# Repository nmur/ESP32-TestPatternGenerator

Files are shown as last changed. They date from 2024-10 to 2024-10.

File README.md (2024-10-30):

# ESP32-TestPatternGenerator

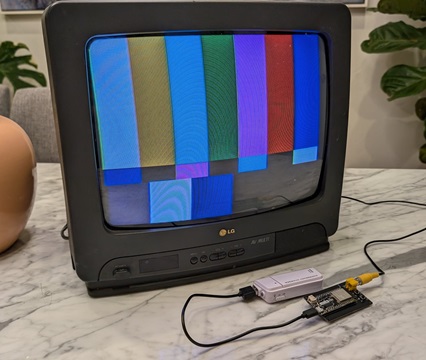
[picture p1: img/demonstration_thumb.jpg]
demonstration
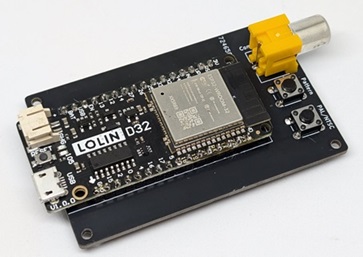
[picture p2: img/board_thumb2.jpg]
board
    

This is a simple test pattern generator that runs on the ESP32 microcontroller and utilises the [ESP32CompositeColorVideo](https://github.com/marciot/ESP32CompositeColorVideo) library to output composite video using either the PAL and NTSC video formats. 

This tool is aimed to be used as a quick and portable was of performing tests of basic functionality for CRT TVs.

Its main features are:
- **Cheap**: Approximately <$10 USD in parts
- **Accessible**: Open source. Only a few components so soldering is easy for a first timer.
- **Small**: Roughly 2x3"/45x80mm in size.
- **Fast**: Boots and changes patterns instantly.
- **Portable**: Very low power draw, works with a powerbank or rechargeable LiPo battery.
- **Versatile**: Supports NTSC and PAL, and provides multiple test patterns.

For a similar tool aimed at 15kHz RGB video, see the [RP2040-TestPatternGenerator](https://github.com/nmur/RP2040-TestPatternGenerator).
## BOM

1. LOLIN D32 board ([Official LOLIN AliExpress store](https://www.aliexpress.us/item/2251832622236364.html), [cheaper listings](https://www.aliexpress.us/item/3256806060247101.html) may be available)
	1. 2x 16 pin headers are usually included
2. 2x 6mm push buttons ([AliExpress](https://www.aliexpress.us/item/2261799870049698.html))
3. Female composite jack ([AliExpress](https://www.aliexpress.us/item/2255800475452071.html))
4. Composite video cable if you don't already have one ([AliExpress](https://www.aliexpress.us/item/3256806419160332.html))
## Building a Board

1. Download the latest [Gerber zip file](https://github.com/nmur/ESP32-TestPatternGenerator/blob/main/plots/ESP32-TestPatternGenerator.zip).
2. Upload and print the Gerber file to a PCB manufacturing website (such as JLCPCB or PCBWay).
3. Solder the components into their marked positions. 

The circuit is simple enough that a PCB isn't necessary, especially if you would just like to try the tool out first with a breadboard or protoboard. You can even splice a composite video cable and wire the ends directly to the ESP32 board pins, and you can omit the buttons if you don't need every pattern (the tool remembers the last video format).

The schematic is available [here](https://raw.githubusercontent.com/nmur/ESP32-TestPatternGenerator/refs/heads/main/img/schematic.png).
## Uploading the Firmware

Navigate to the [Installation page](https://nmur.github.io/ESP32-TestPatternGenerator-WebInstaller/) to connect to your device and flash the firmware from your browser directly. You'll need to install [CH340 drivers](https://www.wch-ic.com/downloads/CH341SER_ZIP.html) in order

## How to Use

Power the device using USB or and LiPo battery, and connect the composite cable to you CRT TV. Cycle through test patterns with the `Pattern` button, and toggle between video formats with the `PAL/NTSC` button. 

The device will remember the last video format so you don't need to toggle it to your region every time it boots.
## Limitations

Currently the available colours are limited to a palette of 256 colours. As such, noticeable colour banding will be present.

## Compiling

1. Clone the repository
2. Open the `ESP32-TestPatternGenerator.ino` file with the Arduino IDE
3. Install version 1.0.6 of the ESP32 board manager
4. Connect your device via USB
5. Build and upload the program

## Acknowledgements

- [bitluni](https://www.youtube.com/@bitluni) for his original [ESP32CompositeVideo](https://github.com/bitluni/ESP32CompositeVideo) project
- [marciot](https://github.com/marciot) for his [ESP32CompositeColorVideo](https://github.com/marciot/ESP32CompositeColorVideo) library forked from the original project above
- [rossumur](https://github.com/rossumur) for his work on the [ESP_8_BIT](https://github.com/rossumur/esp_8_bit) project
- [Artemio Urbina](https://github.com/ArtemioUrbina) for his test patterns

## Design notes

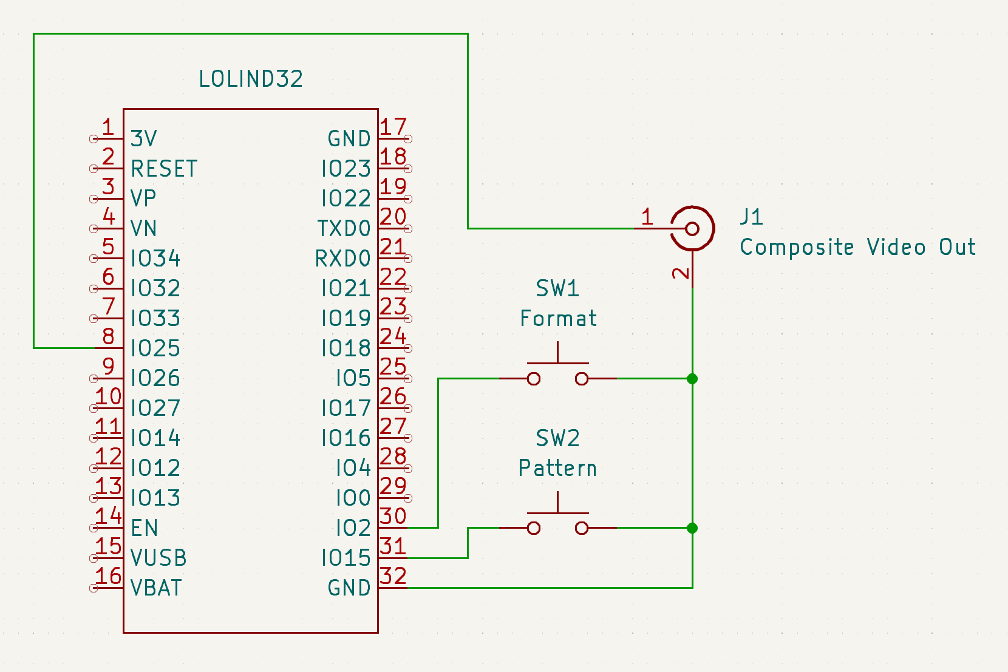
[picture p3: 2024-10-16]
img/schematic.png

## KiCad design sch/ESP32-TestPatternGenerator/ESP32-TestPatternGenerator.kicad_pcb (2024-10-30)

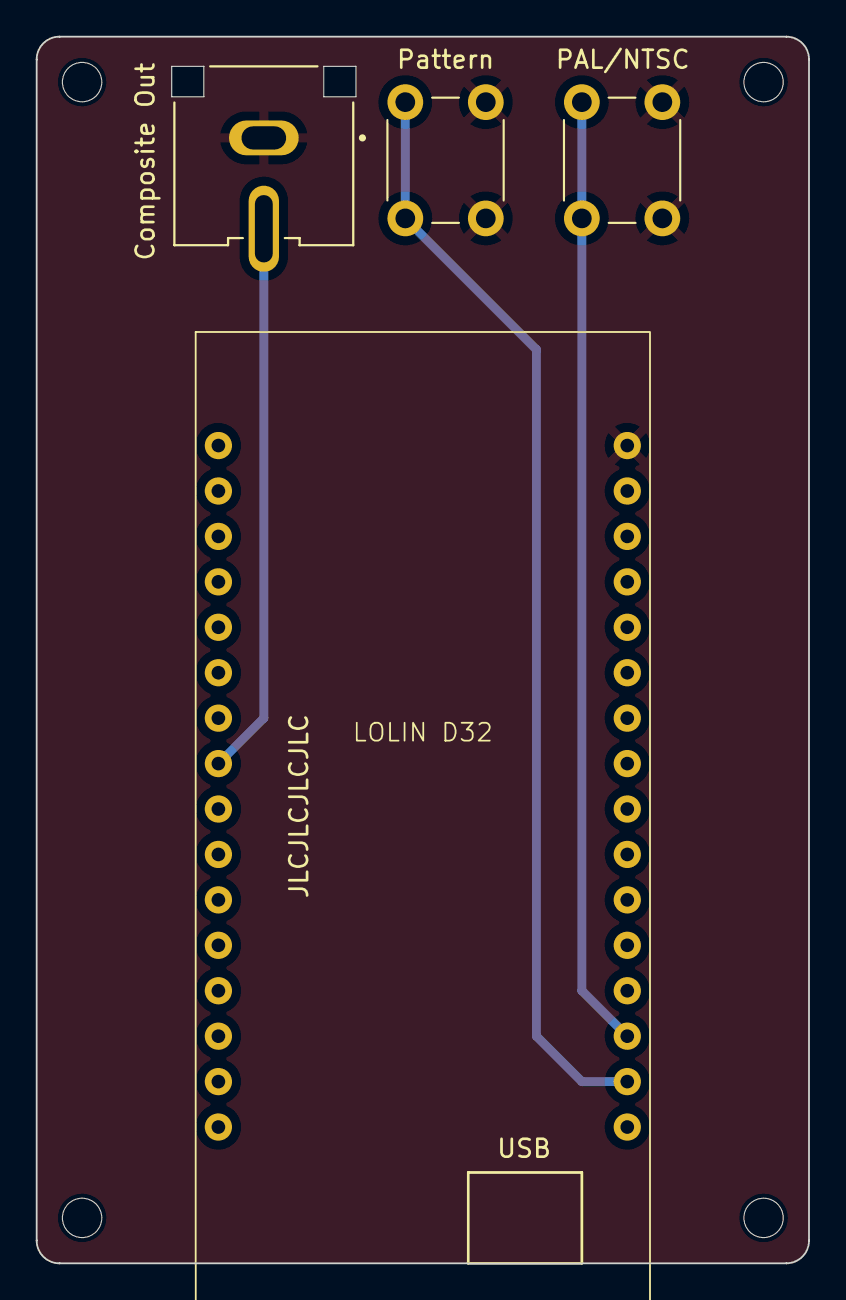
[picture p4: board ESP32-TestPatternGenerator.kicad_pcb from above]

Board: 2 copper layers, 43.2 x 68.6 mm, 4 parts (0 on the bottom side), 3 nets.

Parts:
Composite Out: Composite Out; CUI_RCJ-044
LOLIN D32: LOLIN_D32
PAL/NTSC: Format; SW_PUSH_6mm_H4.3mm
Pattern: Pattern; SW_PUSH_6mm_H4.3mm

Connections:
unnamed: Composite Out.1 (In), LOLIN D32.8 (IO25)
unnamed: LOLIN D32.30 (IO2), PAL/NTSC.1
unnamed: LOLIN D32.31 (IO15), Pattern.1

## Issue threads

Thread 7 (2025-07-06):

Screen shifted to left

DarthI88, 2025-07-06:
How to remedy screen shift on this device?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

nmur, 2025-07-07:
If you're asking how to adjust the geometry on your particular CRT, then that would require looking into the service manual and seeing how you can make adjustments (might be either through a service menu or potentiometers on the main PCB inside)

If you're asking why picture from this tool is shifted slightly compared to some of your other consoles, I believe that this could be due to different tools/consoles generating video signals slightly differently

nmur, 2025-07-07:
Yeah I'm afraid that's not adjustable with this current implementation.

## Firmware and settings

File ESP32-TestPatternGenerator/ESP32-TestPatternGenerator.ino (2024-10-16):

#define USE_ATARI_COLORS
#define SUPPORT_NTSC 1
#define SUPPORT_PAL  1

#include "esp_pm.h"
#include <esp_system.h>

#include <EEPROM.h>

#include "src/gfx/CompositeGraphics.h"
#include "src/gfx/CompositeColorOutput.h"
#include "src/gfx/Image.h"

#include "src/patterns/ColorBars.h"
#include "src/patterns/Grid.h"
#include "src/patterns/Gradients.h"
#include "src/patterns/Circles.h"
#include "src/patterns/White.h"

const int VIDEO_FORMAT_PARAM_ADDR = 0; 
const int VIDEO_FORMAT_PARAM_SIZE = 4;
int videoFormatValue = CompositeColorOutput::NTSC;

CompositeGraphics graphics(CompositeColorOutput::XRES, CompositeColorOutput::YRES);
CompositeColorOutput composite(CompositeColorOutput::NTSC);

Image<CompositeGraphics> testPatterns[] = {
    Image<CompositeGraphics>(colorBars::xres, colorBars::yres, colorBars::pixels),
    Image<CompositeGraphics>(grid::xres, grid::yres, grid::pixels),
    Image<CompositeGraphics>(gradients::xres, gradients::yres, gradients::pixels),
    Image<CompositeGraphics>(circles::xres, circles::yres, circles::pixels),
    //Image<CompositeGraphics>(white::xres, white::yres, white::pixels) // sync issues
};

int testpatternIndex = 0;
int testpatternArraySize = sizeof(testPatterns) / sizeof(testPatterns[0]); 

const int videoFormatPin = 2;

const int testpatternPin = 15;
unsigned long testpatternLastDebounceTime = 0;   
unsigned long testpatternDebounceDelay = 50;     
int testpatternLastButtonState = HIGH;          
int testpatternCurrentButtonState = HIGH;  

void setup() {
  setVideoFormatFromEeprom();

  esp_pm_lock_handle_t powerManagementLock;
  esp_pm_lock_create(ESP_PM_CPU_FREQ_MAX, 0, "compositeCorePerformanceLock", &powerManagementLock);
  esp_pm_lock_acquire(powerManagementLock);
  
  composite.init();
  graphics.init();

  pinMode(videoFormatPin, INPUT_PULLUP);
  pinMode(testpatternPin, INPUT_PULLUP);
}

void drawImage(Image<CompositeGraphics> image) {
  graphics.begin(0);

  image.draw(graphics, 0, 0);
  
  graphics.end();

  composite.sendFrameHalfResolution(&graphics.frame);
}

void loop() {
  drawImage(testPatterns[testpatternIndex]);

  checkAndHandleVideoFormatButtonPress();
  checkAndHandleTestPatternButtonPress();
}

void setVideoFormatFromEeprom() {
  EEPROM.begin(VIDEO_FORMAT_PARAM_SIZE);
  EEPROM.get(VIDEO_FORMAT_PARAM_ADDR, videoFormatValue);
  
  if (videoFormatValue == CompositeColorOutput::NTSC) {
    composite = CompositeColorOutput(CompositeColorOutput::NTSC);
  } else {
    composite = CompositeColorOutput(CompositeColorOutput::PAL);
  }
}

void checkAndHandleVideoFormatButtonPress() {
  if (digitalRead(videoFormatPin) == LOW) {
    if (videoFormatValue == CompositeColorOutput::PAL) {
      EEPROM.put(VIDEO_FORMAT_PARAM_ADDR, CompositeColorOutput::NTSC); 
    } else {
      EEPROM.put(VIDEO_FORMAT_PARAM_ADDR, CompositeColorOutput::PAL);  
    }
    EEPROM.commit();
    delay(200);
    esp_restart();
  }
}

void checkAndHandleTestPatternButtonPress() {
  int buttonState = digitalRead(testpatternPin); 

  if (buttonState != testpatternLastButtonState) {
    testpatternLastDebounceTime = millis();
  }

  if ((millis() - testpatternLastDebounceTime) > testpatternDebounceDelay) {
    if (buttonState == LOW && testpatternCurrentButtonState == HIGH) {
      testpatternIndex++;  
      if (testpatternIndex >= testpatternArraySize) {
        testpatternIndex = 0;  
      }
    }

    testpatternCurrentButtonState = buttonState;
  }

  testpatternLastButtonState = buttonState;
}

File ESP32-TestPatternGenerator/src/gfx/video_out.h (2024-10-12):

/* Copyright (c) 2020, Peter Barrett
**
** Permission to use, copy, modify, and/or distribute this software for
** any purpose with or without fee is hereby granted, provided that the
** above copyright notice and this permission notice appear in all copies.
**
** THE SOFTWARE IS PROVIDED "AS IS" AND THE AUTHOR DISCLAIMS ALL
** WARRANTIES WITH REGARD TO THIS SOFTWARE INCLUDING ALL IMPLIED
** WARRANTIES OF MERCHANTABILITY AND FITNESS. IN NO EVENT SHALL THE AUTHOR
** BE LIABLE FOR ANY SPECIAL, DIRECT, INDIRECT, OR CONSEQUENTIAL DAMAGES
** OR ANY DAMAGES WHATSOEVER RESULTING FROM LOSS OF USE, DATA OR PROFITS,
** WHETHER IN AN ACTION OF CONTRACT, NEGLIGENCE OR OTHER TORTIOUS ACTION,
** ARISING OUT OF OR IN CONNECTION WITH THE USE OR PERFORMANCE OF THIS
** SOFTWARE.
*/

/**
 * Change log:
 *
 * Oct 2021 - Original code from https://github.com/rossumur/esp_8_bit
 *            Modified by Marcio Teixeira to extract Atari framebuffer
 *            and make it compatible with Bitluni's code. I don't
 *            really understand this code very well, but there are
 *            some implementation details in the esp_8_bit repo.
 */

#define VIDEO_PIN   26
#define AUDIO_PIN   18  // can be any pin
//#define IR_PIN      0   // TSOP4838 or equivalent on any pin if desired

#include "esp_types.h"
#include "esp_heap_caps.h"
#include "esp_attr.h"
#include "esp_intr_alloc.h"
#include "esp_err.h"
#include "soc/gpio_reg.h"
#include "soc/rtc.h"
#include "soc/soc.h"
#include "soc/i2s_struct.h"
#include "soc/i2s_reg.h"
#include "soc/ledc_struct.h"
#include "soc/rtc_io_reg.h"
#include "soc/io_mux_reg.h"
#include "rom/gpio.h"
#include "rom/lldesc.h"
#include "driver/periph_ctrl.h"
#include "driver/dac.h"
#include "driver/gpio.h"
#include "driver/i2s.h"

#if !defined(SUPPORT_NTSC) && !defined(SUPPORT_PAL)
    #define SUPPORT_NTSC 1
    #define SUPPORT_PAL 1
#endif

#ifdef IR_PIN
#include "ir_input.h"  // ir peripherals
#endif

#define COLORBURST 1

namespace RawCompositeVideoBlitter {

enum VideoStandard {NTSC, PAL};

int _pal_ = 0;

//====================================================================================================
//====================================================================================================
// Color palettes
//
const static uint32_t atari_palette_rgb[256] = {
    0x00000000,0x000F0F0F,0x001B1B1B,0x00272727,0x00333333,0x00414141,0x004F4F4F,0x005E5E5E,
    0x00686868,0x00787878,0x00898989,0x009A9A9A,0x00ABABAB,0x00BFBFBF,0x00D3D3D3,0x00EAEAEA,
    0x00001600,0x000F2100,0x001A2D00,0x00273900,0x00334500,0x00405300,0x004F6100,0x005D7000,
    0x00687A00,0x00778A17,0x00899B29,0x009AAC3B,0x00ABBD4C,0x00BED160,0x00D2E574,0x00E9FC8B,
    0x001C0000,0x00271300,0x00331F00,0x003F2B00,0x004B3700,0x00594500,0x00675300,0x00756100,
    0x00806C12,0x008F7C22,0x00A18D34,0x00B29E45,0x00C3AF56,0x00D6C36A,0x00EAD77E,0x00FFEE96,
    0x002F0000,0x003A0000,0x00460F00,0x00521C00,0x005E2800,0x006C3600,0x007A4416,0x00885224,
    0x00925D2F,0x00A26D3F,0x00B37E50,0x00C48F62,0x00D6A073,0x00E9B487,0x00FDC89B,0x00FFDFB2,
    0x00390000,0x00440000,0x0050000A,0x005C0F17,0x00681B23,0x00752931,0x0084373F,0x0092464E,
    0x009C5058,0x00AC6068,0x00BD7179,0x00CE838A,0x00DF949C,0x00F2A7AF,0x00FFBBC3,0x00FFD2DA,
    0x00370020,0x0043002C,0x004E0037,0x005A0044,0x00661350,0x0074215D,0x0082306C,0x00903E7A,
    0x009B4984,0x00AA5994,0x00BC6AA5,0x00CD7BB6,0x00DE8CC7,0x00F1A0DB,0x00FFB4EF,0x00FFCBFF,
    0x002B0047,0x00360052,0x0042005E,0x004E006A,0x005A1276,0x00672083,0x00762F92,0x00843DA0,
    0x008E48AA,0x009E58BA,0x00AF69CB,0x00C07ADC,0x00D18CED,0x00E59FFF,0x00F9B3FF,0x00FFCAFF,
    0x0016005F,0x0021006A,0x002D0076,0x00390C82,0x0045198D,0x0053279B,0x006135A9,0x006F44B7,
    0x007A4EC2,0x008A5ED1,0x009B6FE2,0x00AC81F3,0x00BD92FF,0x00D0A5FF,0x00E4B9FF,0x00FBD0FF,
    0x00000063,0x0000006F,0x00140C7A,0x00201886,0x002C2592,0x003A329F,0x004841AE,0x00574FBC,
    0x00615AC6,0x00716AD6,0x00827BE7,0x00948CF8,0x00A59DFF,0x00B8B1FF,0x00CCC5FF,0x00E3DCFF,
    0x00000054,0x00000F5F,0x00001B6A,0x00002776,0x00153382,0x00234190,0x0031509E,0x00405EAC,
    0x004A68B6,0x005A78C6,0x006B89D7,0x007D9BE8,0x008EACF9,0x00A1BFFF,0x00B5D3FF,0x00CCEAFF,
    0x00001332,0x00001E3E,0x00002A49,0x00003655,0x00004261,0x0012506F,0x00205E7D,0x002F6D8B,
    0x00397796,0x004987A6,0x005B98B7,0x006CA9C8,0x007DBAD9,0x0091CEEC,0x00A5E2FF,0x00BCF9FF,
    0x00001F00,0x00002A12,0x0000351E,0x0000422A,0x00004E36,0x000B5B44,0x00196A53,0x00287861,
    0x0033826B,0x0043927B,0x0054A38C,0x0065B49E,0x0077C6AF,0x008AD9C2,0x009EEDD6,0x00B5FFED,
    0x00002400,0x00003000,0x00003B00,0x00004700,0x0000530A,0x00106118,0x001E6F27,0x002D7E35,
    0x00378840,0x00479850,0x0059A961,0x006ABA72,0x007BCB84,0x008FDE97,0x00A3F2AB,0x00BAFFC2,
    0x00002300,0x00002F00,0x00003A00,0x00004600,0x00115200,0x001F6000,0x002E6E00,0x003C7C12,
    0x0047871C,0x0057972D,0x0068A83E,0x0079B94F,0x008ACA61,0x009EDD74,0x00B2F189,0x00C9FFA0,
    0x00001B00,0x00002700,0x000F3200,0x001C3E00,0x00284A00,0x00365800,0x00446600,0x00527500,
    0x005D7F00,0x006D8F19,0x007EA02B,0x008FB13D,0x00A0C24E,0x00B4D662,0x00C8EA76,0x00DFFF8D,
    0x00110E00,0x001D1A00,0x00292500,0x00353100,0x00413D00,0x004F4B00,0x005D5A00,0x006B6800,
    0x0076720B,0x0085821B,0x0097932D,0x00A8A43E,0x00B9B650,0x00CCC963,0x00E0DD77,0x00F7F48F,
};
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

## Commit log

2024-10-12 created skeleton arduino project
2024-10-14 initial attempt at switching regions, toggles between PAL/NTSC every 2 secs
2024-10-14 made the video format toggle on button press
2024-10-14 removed unnecessary debounce code (as we restart the device anyway), cleanup/refactor
2024-10-15 loop through all the patterns on a timer
2024-10-16 added button handler to cycle through test patterns (without debounce)
2024-10-16 added schematic including custom symbol library for LOLIN32
    [ESP32-TestPatternGenerator.kicad_pcb, ESP32-TestPatternGenerator.kicad_sch]
2024-10-16 first pass of the PCB
    [ESP32-TestPatternGenerator.kicad_pcb, ESP32-TestPatternGenerator.kicad_sch]
2024-10-16 finalised PCB
    [ESP32-TestPatternGenerator.kicad_pcb]
2024-10-16 added v1.0 gerber
    [ESP32-TestPatternGenerator-B_Cu.gbl, ESP32-TestPatternGenerator-B_Mask.gbs, ESP32-TestPatternGenerator-B_Paste.gbp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]
2024-10-16 minor changes
    [ESP32-TestPatternGenerator.kicad_pcb, ESP32-TestPatternGenerator.kicad_sch]
2024-10-30 increased composite pin hole clearance
    [ESP32-TestPatternGenerator.kicad_pcb]
2024-10-30 added JLCPCB order number marker and USB positioning aid labels on silkscreen
    [ESP32-TestPatternGenerator.kicad_pcb]
2024-10-30 exported v1.1 gerber
    [ESP32-TestPatternGenerator-B_Cu.gbl, ESP32-TestPatternGenerator-B_Mask.gbs, ESP32-TestPatternGenerator-B_Paste.gbp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]
